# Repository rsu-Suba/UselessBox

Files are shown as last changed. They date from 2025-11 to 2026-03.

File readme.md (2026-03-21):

## メインファイル
- コード [ONOFF_V2](./ONOFF_V4/ONOFF_V4.ino)
- 回路画像 [OnOffBread.png](./OnOffBread.PNG.png)
- PCB画像(不使用) [OnOff.brd](./OnOff2.brd)
- 3Dモデル(Ver2) [OnOff3D.f3d](./OnOff3D.f3d)
---
### 2020年

### 2月
製作開始 (2/8/2020)  
Ver1 (2/11/2020)
- Arduino Uno 3
- 蓋サーボとスイッチサーボが同じアーム  
- すべてアクリル板  
- 電池単1.5*2  

### 3月

Ver2 (3/2/2020)
- Arduino Nano Every
- 蓋サーボとスイッチサーボを分離
- すべてアクリル板
- 電池9V*1

Ver3 (3/12/2020)
- Arduino Nano Every
- Ver2の改良版
- 基盤、配線、スイッチ、マイコンを一つの基盤に移植
- すべてアクリル板
- 電池9V : 1 | 1.5V : 4

### 4～5月
アルミ土台を設計

### 7月
Ver4 (7/19/2020)
- Arduino Pro Mini
- リセットボタン、RGBLED追加
- サーボのスピード変更可にした
- アルミ土台、外側だけアクリル板
- 電池9V : 1 | 1.5V : 4
---
### 2021年

### 10月
16x8ドットマトリクステスト

---
#### Inspired by [全力でスイッチをONするとOFFするロボットと戦ってみた](https://youtu.be/bOD2-mRphTI)

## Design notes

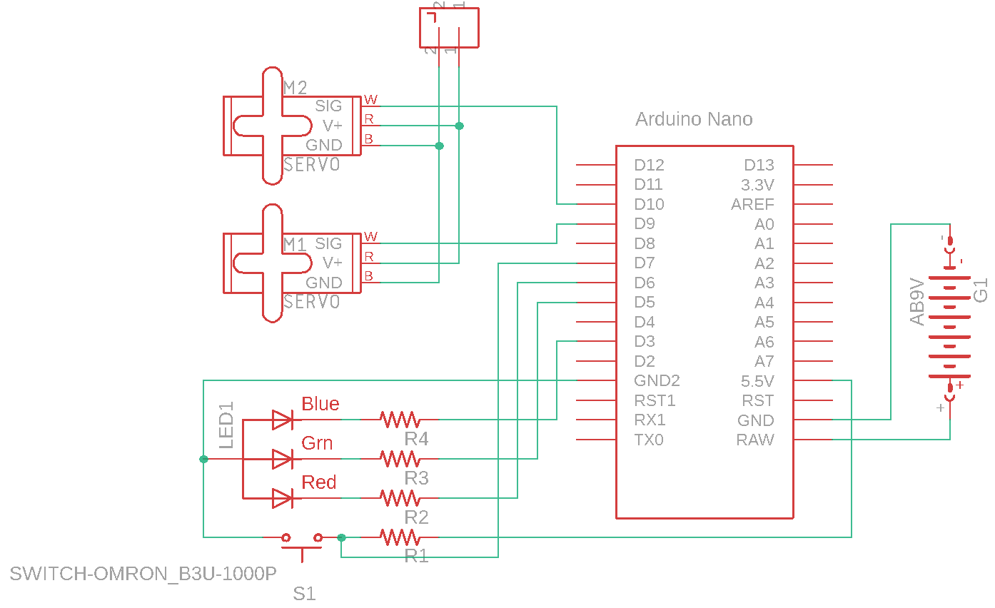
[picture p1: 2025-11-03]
ONOFFSch.png

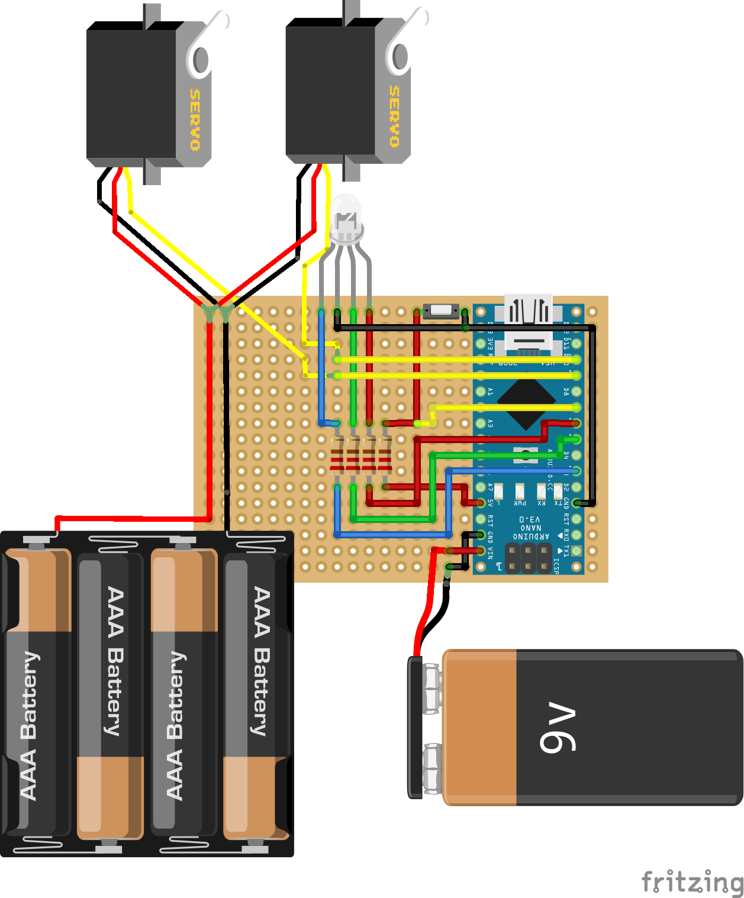
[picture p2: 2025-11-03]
OnOffBread.PNG.png

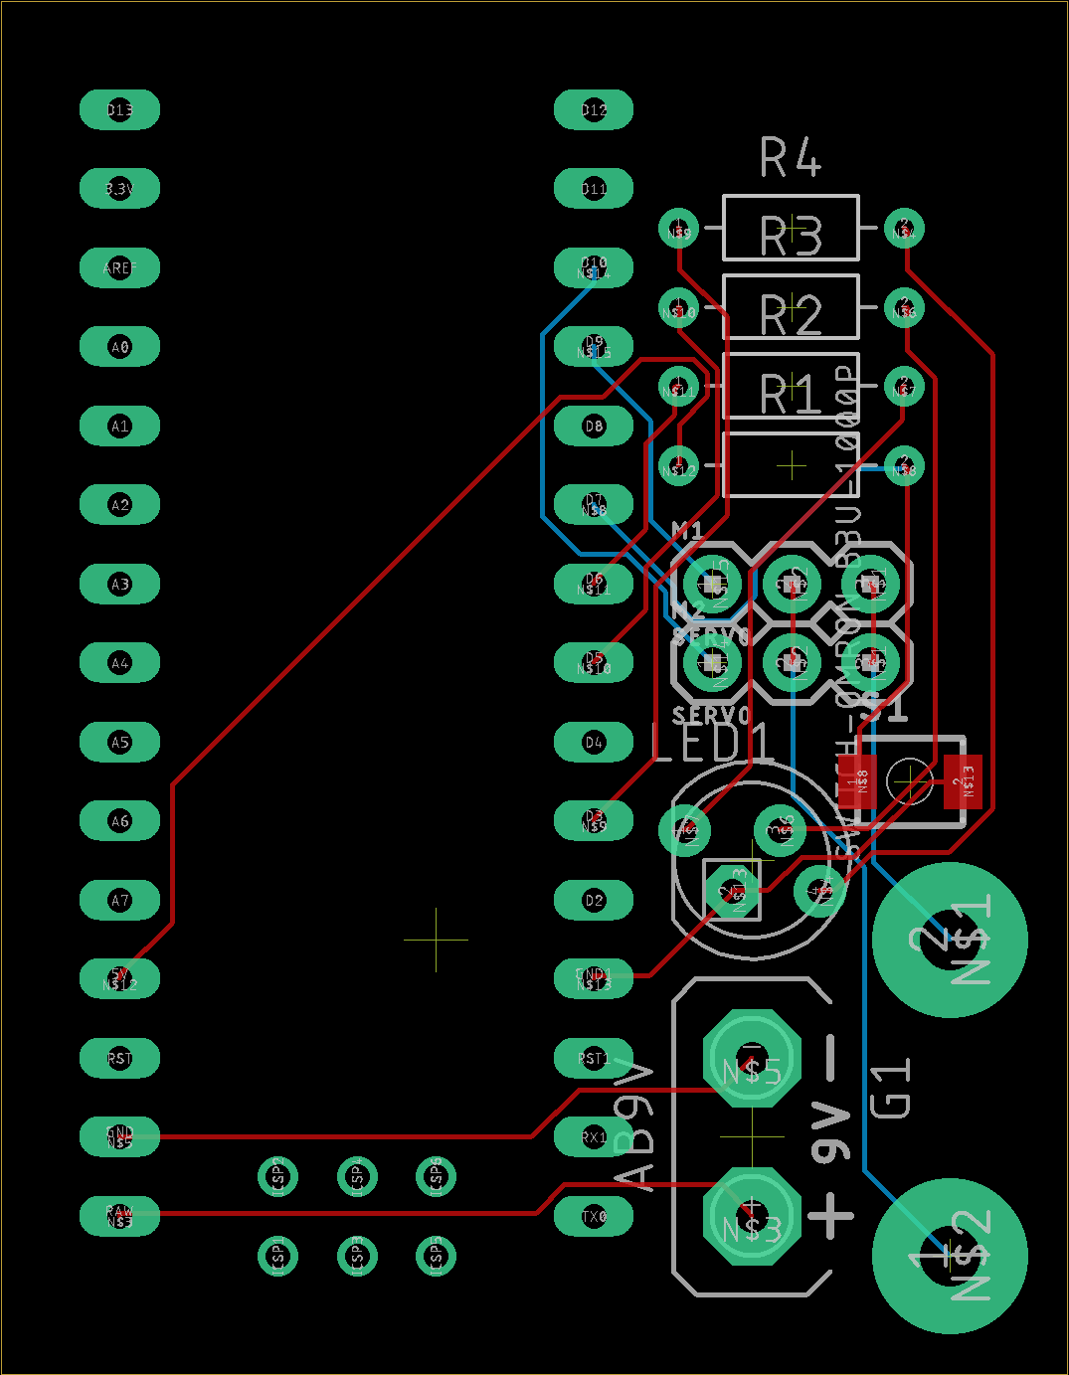
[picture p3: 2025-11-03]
ONOFFPCBBoard.png

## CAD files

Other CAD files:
OnOff3D.f3d

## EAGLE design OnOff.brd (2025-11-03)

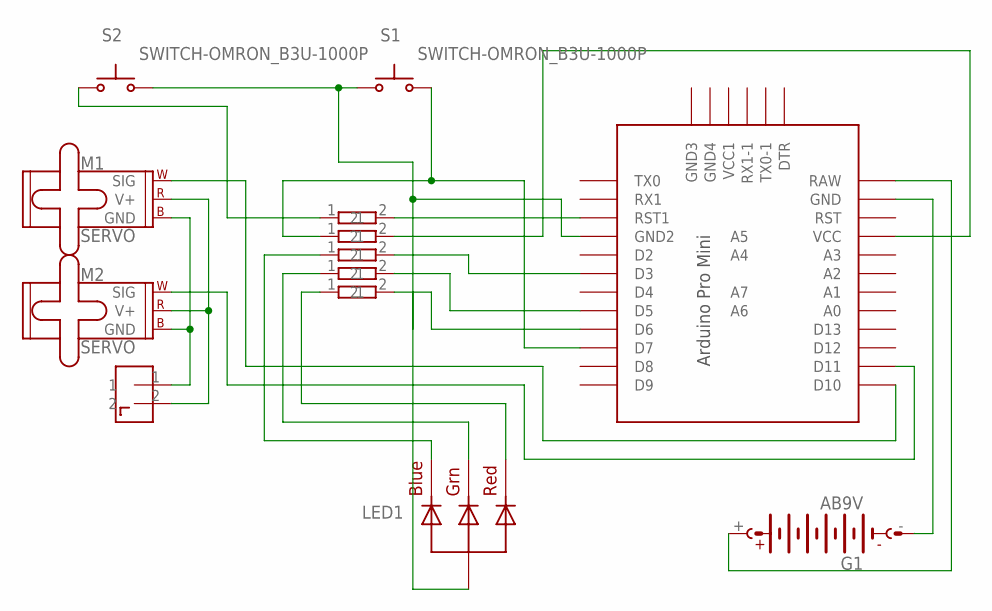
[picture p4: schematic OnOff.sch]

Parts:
CONNECTOR1: 2PIN
CONNECTOR2, CONNECTOR3, CONNECTOR4, CONNECTOR5, CONNECTOR6: RESISTER; RESISTER_SOCKET
G1: AB9V
LED1: RGBLED_CA-5MM; LED5MMRGB
M1, M2: SERVO; 1X03
S1, S2: SWITCH-OMRON_B3U-1000P
U$1: PRO-MINI-2

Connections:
unnamed: G1.-, U$1.GND
unnamed: G1.+, U$1.RAW
unnamed: CONNECTOR1.1, M1.3 (GND), M2.3 (GND)
unnamed: CONNECTOR1.2, M1.2 (V+), M2.2 (V+)
unnamed: CONNECTOR4.1, LED1.4 (BLUE)
unnamed: CONNECTOR5.1, LED1.3 (GREEN)
unnamed: CONNECTOR6.1, LED1.1 (RED)
unnamed: CONNECTOR6.2, U$1.D6
unnamed: CONNECTOR5.2, U$1.D5
unnamed: CONNECTOR4.2, U$1.D3
unnamed: CONNECTOR3.1, S1.2 (S), U$1.D7
unnamed: CONNECTOR2.2, U$1.RST1
unnamed: CONNECTOR2.1, S2.1
unnamed: M2.1 (SIG), U$1.D11
unnamed: M1.1 (SIG), U$1.D10
unnamed: LED1.2 (VCC), S1.1, S2.2 (S), U$1.GND1 (GND2)
unnamed: CONNECTOR3.2, U$1.VCC

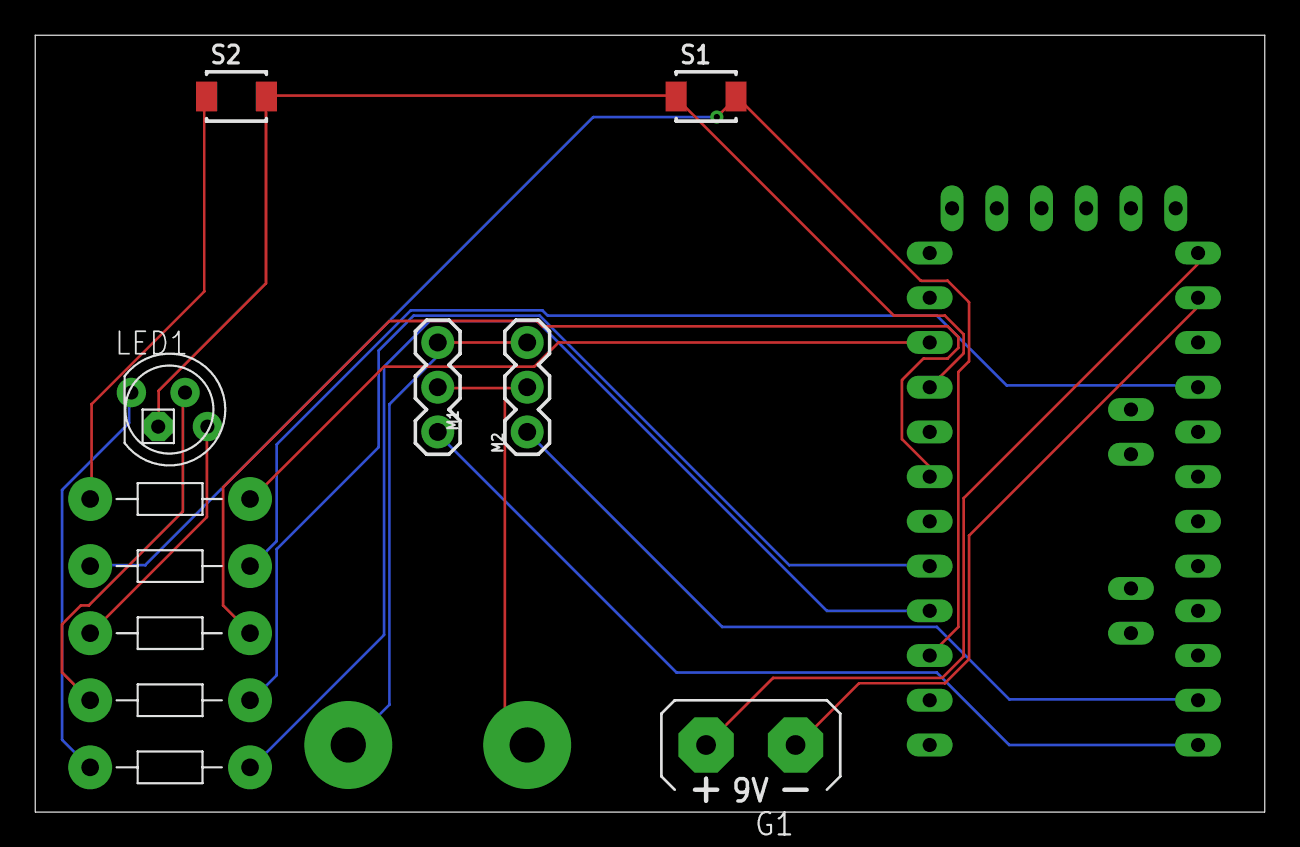
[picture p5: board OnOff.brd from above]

Board: 2 copper layers, 69.8 x 44.1 mm, 13 parts (0 on the bottom side), 17 nets.

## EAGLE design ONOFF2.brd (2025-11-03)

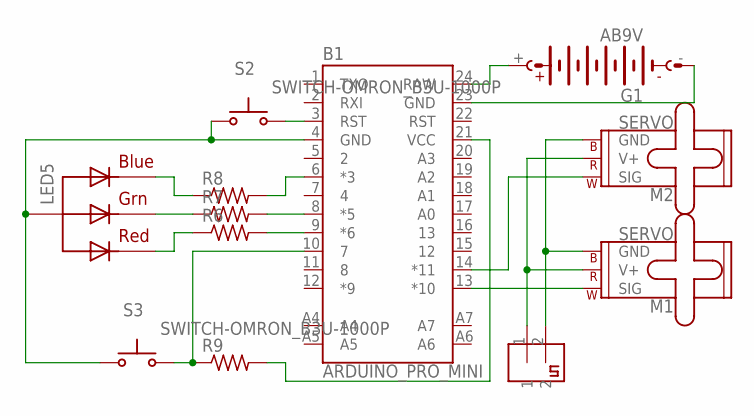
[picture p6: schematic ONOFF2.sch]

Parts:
B1: ARDUINO_PRO_MINI
CONNECTOR1: 2PIN
G1: AB9V
LED5: RGBLED_CA-5MM; LED5MMRGB
M1, M2: SERVO; 1X03
R6, R7, R8, R9: R-US_AXIAL-7.2MM-PITCH; RESAD724W46L381D178B
S2, S3: SWITCH-OMRON_B3U-1000P

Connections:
unnamed: B1.23 (GND), G1.-
unnamed: CONNECTOR1.2, M1.3 (GND), M2.3 (GND)
unnamed: B1.4 (GND), LED5.2 (VCC), S2.1, S3.1
unnamed: CONNECTOR1.1, M1.2 (V+), M2.2 (V+)
unnamed: B1.13 (*10), M1.1 (SIG)
unnamed: B1.14 (*11), M2.1 (SIG)
unnamed: LED5.4 (BLUE), R8.1
unnamed: LED5.3 (GREEN), R7.1
unnamed: LED5.1 (RED), R6.1
unnamed: B1.10 (7), R9.1, S3.2 (S)
unnamed: B1.9 (*6), R6.2
unnamed: B1.8 (*5), R7.2
unnamed: B1.6 (*3), R8.2
unnamed: B1.3 (RST), S2.2 (S)
unnamed: B1.21 (VCC), R9.2
unnamed: B1.24 (RAW), G1.+

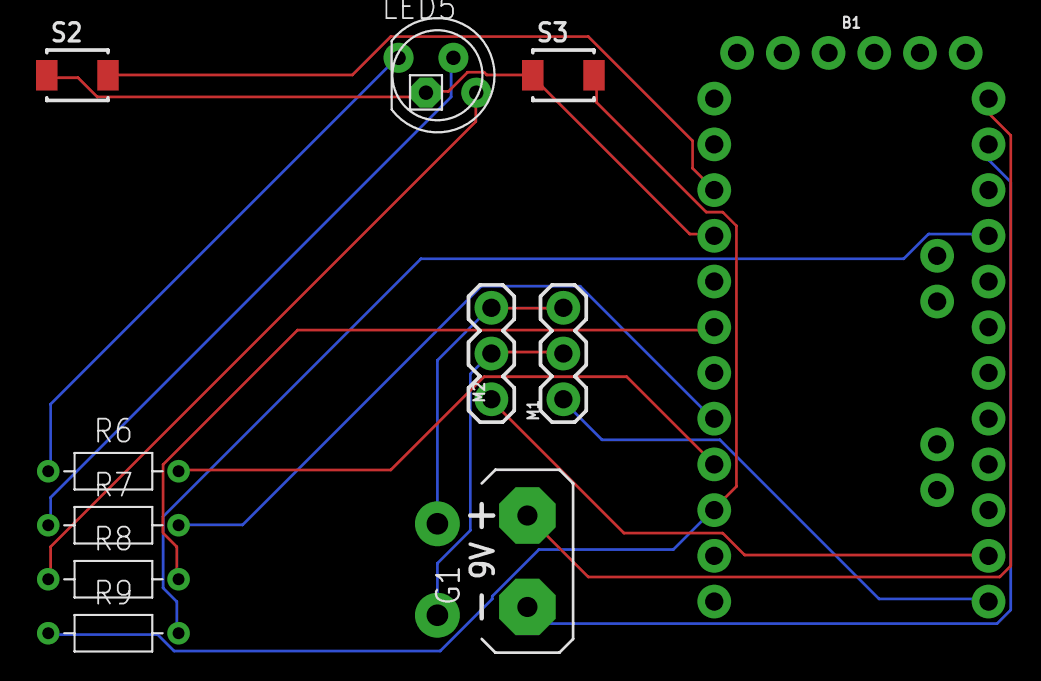
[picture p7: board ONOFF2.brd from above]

Board: 2 copper layers, 12 parts (0 on the bottom side), 16 nets.

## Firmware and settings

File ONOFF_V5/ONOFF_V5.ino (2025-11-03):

#include <VarSpeedServo.h>
#include <MD_Parola.h>
#include <MD_MAX72xx.h>

//ドットマトリクス
#define HARDWARE_TYPE MD_MAX72XX::FC16_HW //デバイス種別
#define MAX_DEVICES 2     //8x8のマトリクス表示のユニット数
#define DATA_PIN  11      //DATA
#define CS_PIN    10      //CS
#define CLK_PIN   13      //CLK
MD_Parola dot = MD_Parola(HARDWARE_TYPE, CS_PIN, MAX_DEVICES);


VarSpeedServo servos;
VarSpeedServo servoh;
int all;
int mode;
int r;
int g;
int b;
int rgb;
int ss;
int sh;
int es;
int eh;
int mode = 1;
bool ok = true;

void setup(){
  Serial.begin(9600);
  s(255,255,255);
  servos.attach(11);
  servoh.attach(10);
  pinMode(6,OUTPUT);
  pinMode(5,OUTPUT);
  pinMode(3,OUTPUT);
  pinMode(7,INPUT);
  all = 0;
  mode = 1;
  eh = 105;
  es = 100;
  sh = 175;
  ss = 0;
  servos.write(ss,255,true);
  servoh.write(sh,255,true);
  s(255,0,0);
  delay(300);
  s(0,255,0);
  delay(300);
  s(0,0 ,255);
  delay(300);
  s(255,255,255);
  delay(300);
  s(0,0,0);
  dot.displayReset();
  dot.begin();
  mode = 1;
}

void loop(){
  Serial.print(digitalRead(7));
  Serial.println(all);
  Serial.println(mode);
  if (all >= 20 && all <= 70){
    rgbR();
  }
   if (digitalRead(7) == 0){
    if (ok == true){
      ok = false;
      if (all >= 0 && all <= 19){
        s(0,255,0);
        m1();
      }
      else if (all >= 20 && all <= 60){
        s(255,255,255);
        m2();
      }
      else if (all >= 61 && all <= 140){
        s(255,0,0);
        servoh.write(eh,255,true);
        servos.write(75,255,true);
        m3();
      }
    }
  }
  else if (digitalRead(7) == 1){
    ok = true;
    if (all <= 70){
      servoh.write(sh,255,true);
      servos.write(ss,255,true);
    }
    else if (all >= 71){
      servoh.write(eh,255,true);
      servos.write(75,255,true);
    }
    if (all >= 0 && all <= 19){
      s(0,0,0);
    }
    ok = true;
  }
}
void m1(){
   dot.displayText("o_o", PA_CENTER, 0, 0, PA_PRINT, PA_NO_EFFECT);
   dot.displayAnimate();
   servoh.write(eh,125,true);
   delay(500);
   servos.write(es,125,true);
   delay(250);
   if (digitalRead(7) == 1){
      servos.write(ss,125,true);
      delay(300);
      if (digitalRead(7) == 0){
        all++;
        m1();
      }
      else if( digitalRead(7) == 1){
        servos.write(ss,125,true);
        if (digitalRead(7) == 0){
          all++;
          m1();
        }
        delay(200);
        servoh.write(sh,125,true);
        if (digitalRead(7) == 0){
          all++;
          m1();
        }
        s(0,0,0);
      }
      all++;
   }
   dot.displayText("", PA_CENTER, 0, 0, PA_PRINT, PA_NO_EFFECT);
   dot.displayAnimate();
   mode += 1;
}

void m2(){
  dot.displayText("#`_´", PA_CENTER, 0, 0, PA_PRINT, PA_NO_EFFECT);
  dot.displayAnimate();
  if (mode == 1){
    servoh.write(eh,255,true);
    servos.write(es,255,true);
    delay(100);
    servos.write(ss,255,true);
    servoh.write(eh,255,true);
    mode++;
    all++;
  }
  else if (mode == 2){
    servoh.write(eh,240,true);
    servos.write(es,240,true);
    delay(2000);
    servos.write(ss,20,true);
    delay(1000);
    servoh.write(sh,255,true);
    mode++;
    all++;
  }
  else if (mode == 3){
    servoh.write(eh,75,true);
    servos.write(es,75,true);
    servos.write(ss,75,true);
    servoh.write(sh,75,true);
    mode++;
    all++;
  }
  else if (mode == 4){
    servoh.write(eh,75,true);
    delay(1000);
    servos.write(es,240,true);
    delay(100);
    servos.write(ss,255,false);
    servoh.write(sh,255,true);
    mode++;
    all++;
  }
  else if (mode == 5){
    servoh.write(eh,150,true);
    servos.write(es,150,true);
    servos.write(ss,150,true);
    delay(2000);
    servos.write(es,255,true);
    delay(2000);
    servos.write(ss,255,true);
    servoh.write(sh,255,true);
    mode++;
    all++;
  }
  else if (mode == 6){
    servoh.write(eh,200,true);
    delay(2000);
    servos.write(es,200,true);
    delay(2000);
    servos.write(ss,200,true);
    delay(2000);
    servoh.write(eh,200,true);
    mode++;
    all++;
  }
  else if (mode == 7){
    servoh.write(eh,240,true);
    servos.write(es,240,true);
    servos.write(65,240,true);
    delay(750);
    servos.write(es,240,true);
    delay(400);
    servos.write(ss,240,true);
    servoh.write(sh,240,true);
    mode++;
    all++;
  }
  else if (mode == 8){
    servoh.write(145,255,true);
    servoh.write(110,255,true);
    servoh.write(157,255,true);
    servoh.write(145,255,true);
    servoh.write(168,255,true);
    servoh.write(134,255,true);
    servoh.write(eh,255,true);
    servos.write(es,255,true);
    delay(100);
    servos.write(ss,255,true);
    servoh.write(sh,255,true);
    mode++;
    all++;
  }
  else if (mode == 9){
    servoh.write(eh,255,true);
    servos.write(73,255,true);
    servos.write(23,255,true);
    servos.write(89,255,true);
    servos.write(12,255,true);
    servos.write(21,255,true);
    servos.write(42,255,true);
    servos.write(es,255,true);
    delay(100);
    servos.write(ss,255,true);
    servoh.write(sh,255,true);
    mode++;
    all++;
  }
  else if (mode == 10){
    servoh.write(145,255,true);
    servos.write(73,255,true);
    servoh.write(110,255,true);
    servos.write(23,255,true);
    servoh.write(157,255,true);
    servos.write(89,255,true);
    servoh.write(145,255,true);
    servos.write(12,255,true);
    servoh.write(168,255,true);
    servos.write(21,255,true);
    servoh.write(134,255,true);
    servos.write(42,255,true);
    servoh.write(eh,255,true);
    servos.write(es,255,true);
    delay(100);
    servos.write(ss,255,true);
    servoh.write(sh,255,true);
    mode = 1;
    all++;
  }
  if (digitalRead(7) == 0){
    all++;
    m2();
  }
  dot.displayText("", PA_CENTER, 0, 0, PA_PRINT, PA_NO_EFFECT);
  dot.displayAnimate();
}

void m3(){
  dot.displayText("(ﾟ∀ﾟ)", PA_CENTER, 0, 0, PA_PRINT, PA_NO_EFFECT);
  dot.displayAnimate();
  servos.write(es);
  if (digitalRead(7) == 1){
    servos.write(75,255,true);
    if (digitalRead(7) == 0){
      servos.write(es);
    }
  }
  dot.displayText("", PA_CENTER, 0, 0, PA_PRINT, PA_NO_EFFECT);
  dot.displayAnimate();
}

void s(int red, int green, int blue){
  analogWrite(3,red);
  analogWrite(5,green);
  analogWrite(6,blue);
}

void sr(){
  analogWrite(3,r);
  analogWrite(5,g);
  analogWrite(6,b);
}

void rgbR(){
  delay(40);
  r = 0;
  g = 0;
  b = 0;
  sr();
  delay(40);
  rgb = random(1,5);
  if (rgb == 1){
    r = 255;
  }
  else if (rgb == 2){
    g = 255;
  }
  else if (rgb == 3){
    b = 255;
  }
  else if (rgb == 4){
    r = 255;
    g = 255;
    b = 255;
  }
  sr();
}

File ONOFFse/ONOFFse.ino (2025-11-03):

#include <Servo.h>

Servo servos;
int all;
int mode;
int es;
int ss;
bool ok = true;

void setup() {
  // put your setup code here, to run once:
  Serial.begin(9600);
  servos.attach(9);
  pinMode(12,OUTPUT);
  pinMode(7,INPUT);
  all = 0;
  mode = 1;
  es = 129;
  ss = 0;
  servos.write(ss);
  digitalWrite(12,LOW);
}

void loop() {
  Serial.println(digitalRead(7));
  // put your main code here, to run repeatedly:
  if (digitalRead(7) == 0){
    if (ok == true){
      ok = false;
      if (all >= 140){
        all = 0;
      }
      Serial.println(all);
    }
    if (all >= 0 && all <= 19){
      v1();
    }
    else if (all >= 20 && all <= 60){
      v2();
    }
    else if (all >= 61 && all <= 140){
      v3();
    }
  }
  else if (digitalRead(7) == 1){
    ok = true;
    servos.write(ss);
  }
}

void v1(){
  digitalWrite(12,HIGH);
  servos.write(es);
  delay(750);
  if (digitalRead(7) == 1){
    servos.write(ss);
    delay(300);
    if (digitalRead(7) == 0){
      all++;
      v1();
    }
    else if (digitalRead(7) == 1){
      servos.write(ss);
    }
  }
  else if (digitalRead(7) == 0){
    all++;
    v1();
  }
  delay(50);
  digitalWrite(12,LOW);
}

void v2(){
  if (mode == 1){
    digitalWrite(12,HIGH);
    servos.write(es);
    delay(500);
    servos.write(ss);
    digitalWrite(12,LOW);
    mode++;
    all++;
  }
  else if (mode = 2){
    digitalWrite(12,HIGH);
    servos.write(es);
    delay(150);
    servos.write(ss);
    digitalWrite(12,LOW);
    mode++;
    all++;
  }
  else if (mode == 3){
    digitalWrite(12,HIGH);
    servos.write(70);
    delay(150);
    servos.write(es);
    delay(150);
    servos.write(ss);
    digitalWrite(12,LOW);
    mode++;
    all++;
  }
  else if (mode == 4){
    digitalWrite(12,HIGH);
    servos.write(80);
    delay(500);
    digitalWrite(12,LOW);
    delay(150);
    digitalWrite(12,HIGH);
    servos.write(65);
    delay(300);
    digitalWrite(12,LOW);
    delay(150);
    digitalWrite(12,HIGH);
    servos.write(es);
    delay(200);
    digitalWrite(12,LOW);
    delay(150);
    digitalWrite(12,HIGH);
    servos.write(ss);
    digitalWrite(12,LOW);
    mode++;
    all++;
  }
  else if (mode == 5){
    digitalWrite(12,LOW);
    servos.write(es);
    delay(250);
    servos.write(ss);
    digitalWrite(12,LOW);
    delay(1000);
    digitalWrite(12,LOW);
    servos.write(es);
    delay(2000);
    servos.write(ss);
    digitalWrite(12,LOW);
    mode++;
    all++;
  }
  else if (mode == 6){
    digitalWrite(12,HIGH);
    servos.write(es);
    delay(2000);
    servos.write(ss);
    digitalWrite(12,LOW);
    mode++;
    all++;
  }
  else if (mode == 7){
    digitalWrite(12,HIGH);
    servos.write(es);
    delay(250);
    servos.write(65);
    digitalWrite(12,LOW);
    delay(500);
    digitalWrite(12,HIGH);
    servos.write(es);
    delay(1500);
    servos.write(ss);
    digitalWrite(12,LOW);
    mode++;
    all++;
  }
  else if (mode == 8){
    digitalWrite(12,HIGH);
    servos.write(65);
    digitalWrite(12,LOW);
    delay(250);
    digitalWrite(12,HIGH);
    servos.write(85);
    digitalWrite(12,LOW);
    delay(250);
    digitalWrite(12,HIGH);
    servos.write(25);
    digitalWrite(12,LOW);
    delay(250);
    digitalWrite(12,HIGH);
    servos.write(es);
    delay(250);
    servos.write(ss);
    digitalWrite(12,LOW);
    mode++;
    all++;
  }
  else if (mode == 9){
    digitalWrite(12,HIGH);
    servos.write(100);
    digitalWrite(12,LOW);
    delay(150);
    digitalWrite(12,HIGH);
    servos.write(90);
    digitalWrite(12,LOW);
    delay(150);
    digitalWrite(12,HIGH);
    servos.write(100);
    digitalWrite(12,LOW);
    delay(150);
    digitalWrite(12,HIGH);
    servos.write(70);
    digitalWrite(12,LOW);
    delay(150);
    digitalWrite(12,HIGH);
    servos.write(90);
    digitalWrite(12,LOW);
    delay(150);
    digitalWrite(12,HIGH);
    servos.write(100);
    digitalWrite(12,LOW);
    delay(150);
    digitalWrite(12,HIGH);
    servos.write(95);
    digitalWrite(12,LOW);
    delay(150);
    digitalWrite(12,HIGH);
    servos.write(es);
    digitalWrite(12,LOW);
    delay(150);
    digitalWrite(12,HIGH);
    servos.write(ss);
    digitalWrite(12,LOW);
    mode++;
    all++;
  }
  else if (mode == 10){
    digitalWrite(12,HIGH);
    servos.write(75);
    digitalWrite(12,LOW);
    delay(150);
    digitalWrite(12,HIGH);
    servos.write(90);
    digitalWrite(12,LOW);
    delay(150);
    digitalWrite(12,HIGH);
    servos.write(100);
    digitalWrite(12,LOW);
    delay(150);
    digitalWrite(12,HIGH);
    servos.write(70);
    digitalWrite(12,LOW);
    delay(150);
    digitalWrite(12,HIGH);
    servos.write(es);
    digitalWrite(12,LOW);
    delay(150);
    digitalWrite(12,HIGH);
    servos.write(95);
    digitalWrite(12,LOW);
    delay(150);
    digitalWrite(12,HIGH);
    servos.write(95);
    digitalWrite(12,LOW);
    delay(150);
    digitalWrite(12,HIGH);
    servos.write(es);
    digitalWrite(12,LOW);
    delay(150);
    digitalWrite(12,HIGH);
    servos.write(ss);
    digitalWrite(12,LOW);
    mode = 1;
    all++;
  }
  if (digitalRead(7) == 0){
    all++;
    v2();
  }
  if (all == 61){
    servos.write(80);
    digitalWrite(12,HIGH);
  }
}

void v3(){
  servos.write(es);
  if (digitalRead(7) == 1){
    delay(75);
    servos.write(80);
  }
  all++;
}

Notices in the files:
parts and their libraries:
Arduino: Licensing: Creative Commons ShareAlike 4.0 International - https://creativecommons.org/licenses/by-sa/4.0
